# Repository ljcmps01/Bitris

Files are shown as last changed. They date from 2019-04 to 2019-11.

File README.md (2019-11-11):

# Bitris
Proyecto de instalaciones industriales
Se trata de un juego el cual consta de controlar los leds de una matriz con un boton, la matriz desplazará un bit de izquierda a derecha 
en la fila superior, el jugador tendrá un boton que al presionarlo dejará caer el bit al fondo de la matriz.
El objetivo del juego es que el jugador llene todas las filas de la matriz pero siempre una fila a la vez; si el jugador comienza a apilar
La siguiente fila sin haber completado la que se encuentra, perderá una vida, a medida que vaya llenando las filas el juego se volverá mas
veloz.

## Changelog:

_28-03 Funcionamiento de la matriz (delay)_

_10-04 Control de la matriz (Habilitacion de que leds prender)_

_11-04 Funcionamiento de la matriz (TIMER)_

_12-04 Multiplexado de la matriz (Prescaler a 1024 con OCR1A=3,5,8)_

_12-04 Control de velocidad de niveles y desplazamiento del jugador_

_12-04 Deteccion del boton del jugador y animacion de caida (velocidad constante)_

_13-04 1er ensamble: Multiplexado+Desplazamiento+boton+caida_

_13-04 Se agrega la capacidad de mantener el led prendido en el fondo tras realizar la animacion de caida_

_13-04 Se le agrega control de vida y nivel (La vida es solo visual y no afecta el juego todavia)_

_17/04 Se creó programa con animaciones basicas, horizontales y verticales_

_17/04 El boton da inicio al primer juego, se agregó animación cuando se pierde y reinicio con el boton_

~~**[Arreglar falso inicio]**~~

_22/04 VerticalClean, HorizontalClean, Blink pasadas a TIMER_

_23/04 animacion de FillUp pasada a TIMER_

_23/04 Renovacion de Bitris con animaciones de inicio, perdida y victoria (En timer), Falso inicio arreglado_

_23/04 Definiciones Globales del juego_

---------------**FIN DEL CUERPO PRINCIPAL**----------------

_24/04 Creado programa de Display de vida y nivel con CD4511_

_24/04 Acoplado el control de displays al programa principal_

_30/07 Realizado programa para Arduino UNO_

_30/07 Realizado PCB de placa principal_

_13/08 Realizado PCB de placa displays_

_16/08 Adjuntado informe del proyecto_

_19/08 Agregado Diseño 3D del gabinete_

_03/09 Arreglo de diseño de PCB principal_

_12/09 Diseño 3D de la rampa de las monedas_

_20/09 Diseño 3D de la matriz LED_

_08/10 Diseño 3D divididos en partes del gabinete_

_08/10 Conclusion de codigo Bitris Pago_

_05/11 Se agregó la musica principal del juego_

_06/11 Se realizaron pruebas en protoboard con el parlante para un decente sonido_

_08/11 Se realizó el esquematico del amplificador_

_11/11 Arreglado problemas de la musica_

_11/11 Realizado programa de pago CON MUSICA_

## Bugs/Trabajo por hacer:

### Software 

* **LED fantasma**

* **Doble pulsacion**

* Agregar sonido (Principal hecho, falta perdida de vidas, punto, nivel, fin ganado, gameover)

### Hardware 

* Diseñar amplificador (PCB)

* Montar placas (Resta amplificador)

## Creadores

Alejo Rodrigo Campos (@ljcmps01):

* -_Primer programa de control Arduino MEGA_-

* -_Primer diseño SCH y PCB_-

* -_Modelos en 3D_-

Alex Obregon (@alobre4148):

* -_Programa compatible Arduino UNO_ (Programa a utilizar para producto final)-

* -_Diseño PCB final placa principal_-

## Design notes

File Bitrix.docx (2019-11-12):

# Bitrix

El informe deberá tener como mínimo:

1) Caratula con nombre del proyecto y datos de los integrantes
2) Objetivo
3) Breve descripción (esquemas, diagramas, etc.)
4) Principio de funcionamiento y fundamentos teóricos (ecuaciones, graficos,etc)
5) Circuitos electronics (esquemáticos)
6) Modelo de circuito impreso (PCB) lado de cobre y componentes
7) Lista de componentes, costos
8) Posibles aplicaciones
9) Indice

# Introducción

Este proyecto propone crear un Tetris “de un bit”, a diferencia del Tetris común, este no tendrá formas complejas como la L,T, el cubo o el palo; únicamente dispondrá de un único punto (un led) que ira de izquierda a derecha en lo más alto de la pantalla. Una vez el jugador apriete un botón, se dejará caer este bit a lo más profundo de la pantalla, el objetivo es que el jugador vaya alineando horizontalmente bit por bit como se muestra en el siguiente gráfico.

1 | | | 9

Una vez la fila es completada el jugador pasará de nivel y deberá proseguir a llenar la siguiente fila, a medida que el desplazamiento del bit superior va aumentando de velocidad.

El desafío del juego se encuentra en que el jugador NO debe comenzar a llenar la siguiente fila sin haber completado la anterior (ejemplo en el grafico debajo). Si esto llegara a suceder el jugador perderá una de sus vidas.

| | | | | | | El jugador comenzó a completar la 2da
| | | | | | | Fila sin completar la 1ra
0 | | | | | | 8

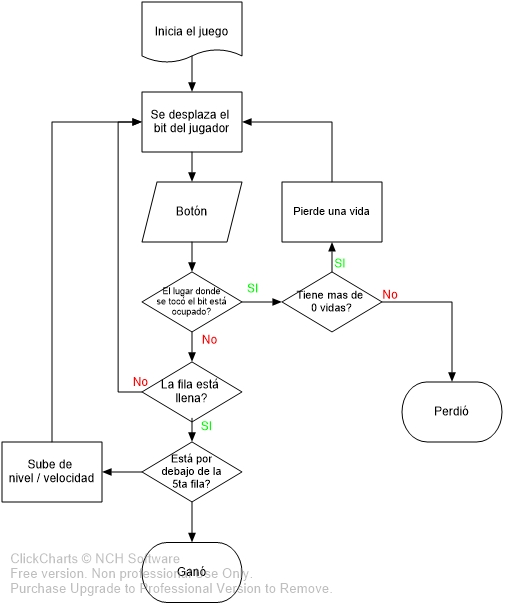
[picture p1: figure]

Debido a que a medida que suba de nivel se aumentará la velocidad de desplazamiento, al jugador se le hará más difícil completar adecuadamente las filas.

Para tener una mayor comprensión del funcionamiento y de lo que se encargará el futuro programa, se realizó el siguiente diagrama de flujo simplificado

El gabinete del juego está hecho a partir de un metro cuadrado de chapa galvanizada de 0,3mm de espesor.

Pero a su vez también se realizaron los diseños de los mismos utilizando AutoCAD para poder visualizar el aspecto final del gabinete y ayudar a la hora de toma de decisiones en cuanto a la estética del proyecto y comodidad para el usuario.

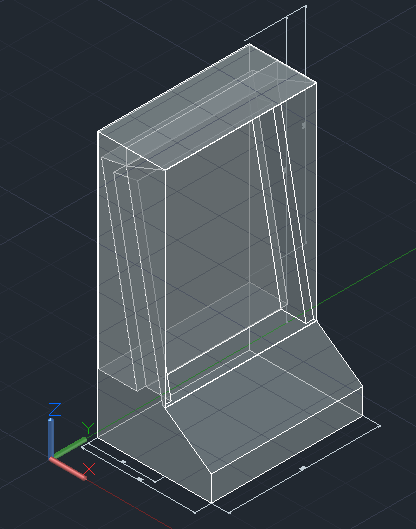
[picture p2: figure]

Esto nos permitió tener acceso a figuras 3D que pueden ser impresas fácilmente en una impresora 3D

# Principio de funcionamiento

## Matriz y multiplexado

Debido a la limitada cantidad de pines disponibles en el microcontrolador y a la poca energía que estos pueden entregar en su salida, se debió utilizar técnicas de multiplexado, tanto para el control de la matriz 6x4 como para los displays de vida restantes y nivel.

Para esto se utilizó uno de los timer del ATMEGA 328p en modo de comparación con un prescaler de 1024 y un valor de comparador de 3. Con esto en una frecuencia de aproximadamente 16MHz nos da una función de multiplexado que se activa cada:

1/(16MHz)×1024×3=0,000192 seg

O sea, con una frecuencia de:

1/(192μSeg)=5,2KHz

Si bien esto está muy por encima de la frecuencia de 50Hz necesaria para que el ojo humano no distinga el prendido y apagado, se optó por esta velocidad ya que el programa debe realizar el maskeo completo de la matriz y modificar los valores de los displays dentro de estos intervalos.

Por lo que la frecuencia real de multiplexado completo es el intervalo entre cada activación de la función dividido cada led de la matriz:

(5,2KHz)/(4×6)=217Hz

Si bien sigue siendo más de 4 veces la velocidad requerida, preferimos utilizarla de todas maneras ya que no afecta el funcionamiento del juego y a la vez conseguimos una visualización del display más limpia que a frecuencias más bajas.

## Display de vidas y nivel

Como se mencionó en el punto anterior, los displays son controlados en parte por multiplexación para mostrar las vidas restantes y el nivel actual.

Pero se presentó la problemática de la cantidad de pines limitados del ATMEGA328p por lo que no era posible controlar directamente los 7 segmentos a través de él utilizando una decodificación por software. En cambio, se decidió utilizar un CD4511 de intermediario.

El CD4511 es un decodificador de binario a 7 segmentos, lo que quiere decir que una vez conectado las entradas correspondientes y las salidas a su respectivo segmento, en el display se vera el numero ingresado en formato binario en las entradas.

De esta forma se ahorran 3 pines que pueden ser utilizados para otras funciones, el programa se simplifica ya que solo hay que poner las salidas en binario, y mas importante, se libera al microcontrolador de la carga de tener que alimentar los 7 segmentos del display, ya que estos serán controlados por el mismo CD4511, el cual es capaz de soportar mayores cargas.

Cabe aclarar dos cosas:

- Debido a este último aspecto se debe poner resistencias para proteger los segmentos
- El microcontrolador se sigue encargando de controlar que display prender (multiplexado) y que valor mostrar (Se lo indica al CD4511)

## Botón

### Jugador

Debido a que este es un juego de reflejos y velocidad nos pareció que debíamos evitar utilizar la técnica de polling* para detectar cuando se presiona el botón. En cambio, se tomo ventaja de una de las interrupciones externas del ATMEGA328p, de esta forma el programa dentro del microcontrolador reaccionará de forma casi instantánea cada vez que el botón sea presionado.

*Consiste en realizar una lectura lo mas frecuentemente posible del estado un pin para determinar si hubo un cambio de estado

Esta interrupción será activada cuando ocurra un flanco descendente en el pin 4 del microcontrolador.

Para la elección del botón se tomó como principal parámetro la estética y sensación del mismo al presionarlo.

### Monedas

En el caso de la detección de monedas se optó por realizar una ranura en el frontal del gabinete que dirija a una rampa que vaya recolectando las monedas insertadas. Dicha rampa tiene un foto-interruptor incrustado el cual detectará el paso de la moneda.

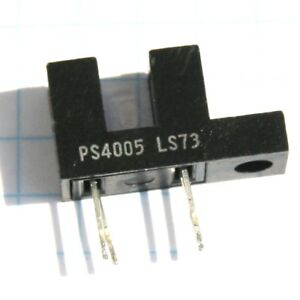
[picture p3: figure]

Se decidió utilizar un PS4005 por su simplicidad de uso.

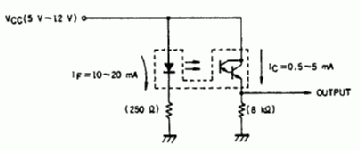
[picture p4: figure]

Como la esquemático interno indica, en su interior no hay más que un LED y un fototransistor

Para hacerlo funcionar de la manera deseada solo se necesita poner unas resistencias de pull up y de limitación de corriente para el LED

El foto-interruptor estará constantemente mandando un 1 en el pin 2 del ATMEGA; cuando pase un objeto entre se el LED y el fototransistor, la señal se irá a masa.

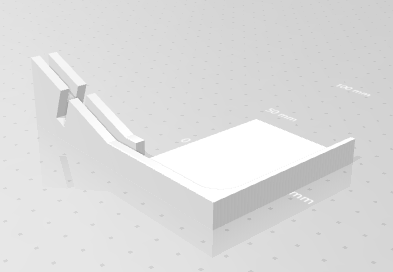
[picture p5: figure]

Por medio del software se configuro que esto solo pueda ser activado para iniciar el juego, durante el resto del juego las señales recibidas por el interruptor serán ignoradas. De la misma forma que las señales recibidas del botón del jugador serán ignoradas hasta que el mismo inserte una moneda/ficha.

La rampa fue realizada en AutoCAD para que pueda ser impresa en 3D fácilmente, con la ranura para el foto-interruptor

## Música/amplificación

Para añadirle más carisma al juego se le puso música de fondo. La cual sonará a través de un parlante de 4 Ω

Esto se realizó utilizando la librería Tone de Arduino, la cual fue creada para este mismo propósito. Aun así, el pin del Arduino no es capaz de hacer sonar el parlante utilizado, o por lo menos no con el volumen deseado.

Por esto se decidió hacer una amplificación simple con un optoacoplador (4n28) y un transistor que soporte la carga presentada por el parlante.

Realizando pruebas se encontró que el parlante puede llegar a consumir hasta 350mA aprox. Con una alimentación de 9V. Teniendo en cuenta esto se decidió utilizar un BD137, el cual es un transistor NPN capaz de soportar una corriente de colector de 1,5A.

Como detalle interactivo, la música cambiará su velocidad a medida que el jugador vaya aumentando de nivel.

# Circuitos electrónicos

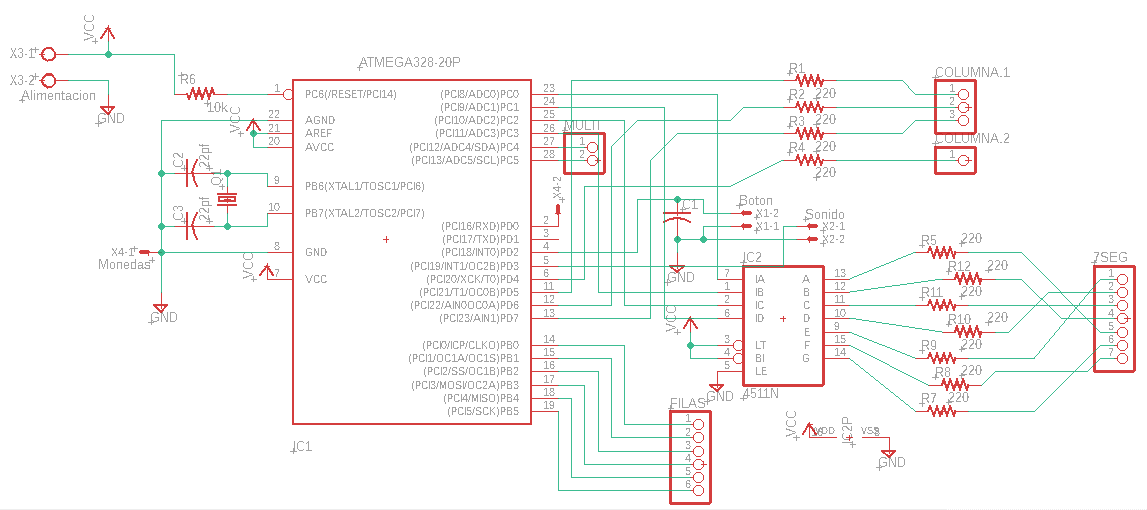
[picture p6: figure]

## Placa controladora

## Placa de displays 7 segmentos

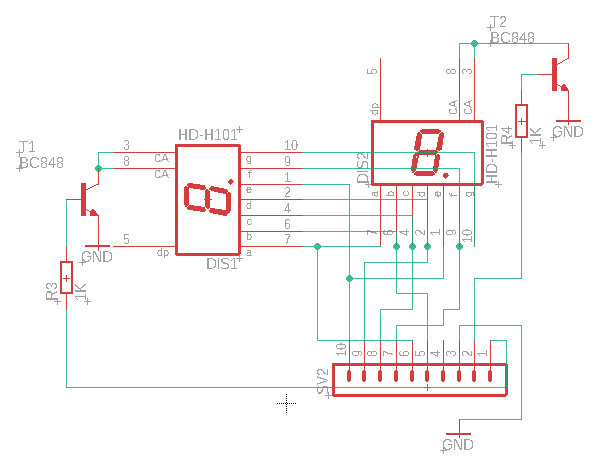
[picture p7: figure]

## Placa de amplificación de audio

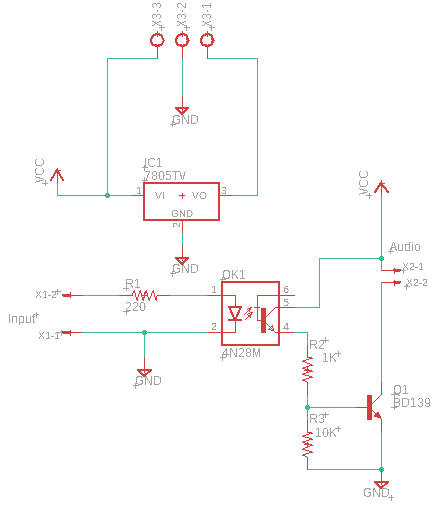
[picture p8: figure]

# Diseño PCB

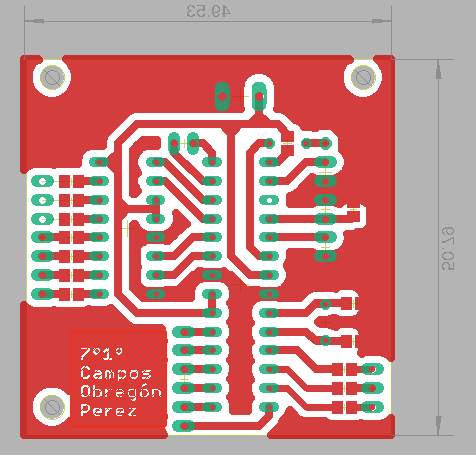
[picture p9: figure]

## Placa controladora

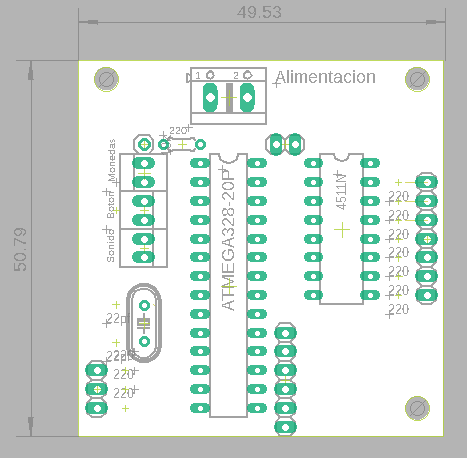
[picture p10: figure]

## Placa de amplificación de audio

## Placa de displays 7 segmentos

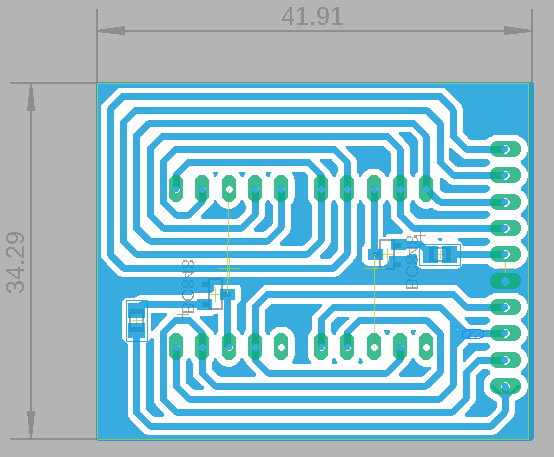
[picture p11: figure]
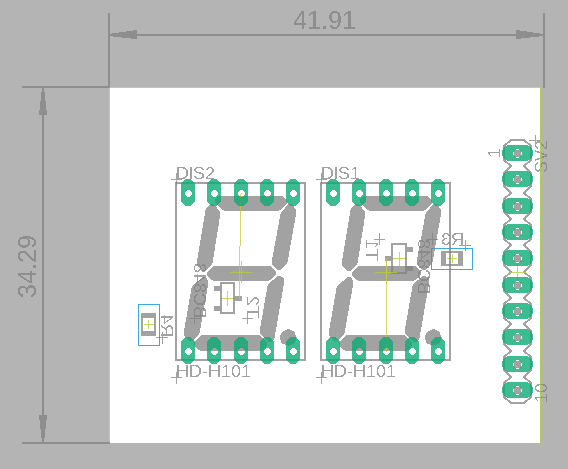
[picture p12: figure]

# Aplicaciones

El Producto en si es solo un juego por lo que no tiene aplicación útil en si, pero es un producto didáctico que como tal puede ser vendido a salones de Arcade.

Ademas si bien el producto planteado como tal puede ser robusto y pesado, este se puede utilizar en diferentes configuraciones

# Lista de componentes

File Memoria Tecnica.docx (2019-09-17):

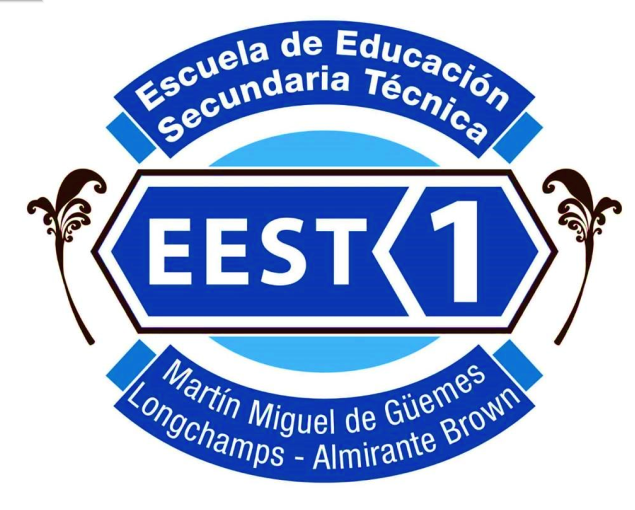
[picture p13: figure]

# Bitrix

Trabajo de instalaciones industriales

Alejo Rodrigo Campos

Alex Obregón

Tomas Perez

7° 1°

27/08

# Introducción

Este proyecto propone crear un Tetris “de un bit”, a diferencia del Tetris común, este no tendrá formas complejas como la L,T, el cubo o el palo; únicamente dispondrá de un único punto (un led) que ira de izquierda a derecha en lo más alto de la pantalla, una vez el jugador apriete un botón, se dejará caer este bit a lo más profundo de la pantalla, el objetivo es que el jugador vaya alineando horizontalmente bit por bit como se muestra en el siguiente gráfico.

1 | | | 9

Una vez la fila es completada el jugador pasara de nivel y deberá proseguir a llenar la siguiente fila, a medida que el desplazamiento del bit superior va aumentando de velocidad.

El desafío del juego se encuentra en que el jugador NO debe comenzar a llenar la siguiente fila sin haber completado la anterior (ejemplo en el grafico debajo). Si esto llegara a suceder el jugador perderá una de sus 3 vidas.

| | | | | | | El jugador comenzó a completar la 2da
| | | | | | | Fila sin completar la 1ra
0 | | | | | | 8

# Características

## Software

El programa del juego será el encargado de realizar el funcionamiento lógico del juego, en la misma ira tanto la configuración del juego (vidas, niveles, velocidad, etc)

Como el lógico del resto del hardware.

### Configuración del juego:

Vidas: determina la cantidad de vidas que tiene el jugador

Selector de nivel: determina en que nivel se encuentra el jugador

Nivel: es un vector que tiene una cantidad de elementos igual a la cantidad de filas de la matriz, cada elemento tiene un valor especifico que determina la velocidad del juego en base a los ciclos que realiza el oscilador del uC.

### Control lógico del hardware

Display: determina que numero muestran los Display de 7 segmentos tomando el valor de las variables Selector de nivel y Vida.

Multiplexado: es una variable boolean que se utiliza para multiplexar los Display

Filas: posee la altura (cantidad de filas) de la matriz y en base a ella se determina la cantidad de niveles del juego, se usará para el control de la matriz y mostrar animaciones junto con Columnas

Columnas: posee el ancho (cantidad de columnas) de la matriz y se usará para el desplazamiento del jugador, y determinar en qué posición se encuentra, también se usará para mostrar animaciones junto con Filas

Sonido: se utiliza para realizar las diferentes melodías del juego

## Hardware:

Posee 3 partes principales ara el funcionamiento del juego, obviando la alimentación.

### Matriz LED

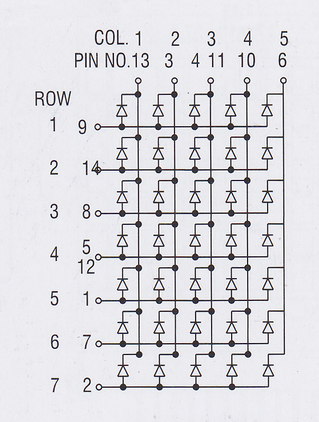
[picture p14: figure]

Se trata de una matriz led de 6x4 la cual será la pantalla del juego por lo cual se trata de la parte mas importante del juego ya que sin ella el jugador no tendría idea de lo que sucede

### Displays

Son dos displays de 7 segmentos ubicados en los extremos del frente del gabinete, uno mostrará las vidas restantes mientras que el otro se encargará de mostrar en el nivel está el jugador, se controlaran mediante un CD4511 que traduce de binario a 7 segmentos y además mediante dos transistores con el fin de multiplexar los valores que mostrará cada display

### Buzzer

Es un piezoeléctrico que se encargará de darle mas “vida” al juego, emitiendo las melodías dependiendo la situación del juego, necesita amplificador?

# Problemáticas

## Consumo

Al haber de por medio una matriz (la cual contiene 24 leds), 2 displays (cada uno de 7 leds) y un parlante piezoeléctrico que deben ser controlados por un uC se debe tener especial cuidado con la corriente que todo esto llegue a exigirle al integrado ya que este es de baja potencia

### Solución

El principal problema se encuentra en la gran cantidad de led a manejar, ya que idealmente el ATMEGA no puede entregar más de 200 mA. La solución mas viable encontrada es el multiplexado para el control de la matriz.

Utilizando esta técnica, la matriz tendrá el consumo equivalente a un solo led a pesar de que visualmente pareciera que la matriz estuviese completamente prendida si así se deseara.

Por otro lado, el uC pasará a ser solo la entrada de un amplificador que se encargará de amplificar la señal para el piezoeléctrico

El control de los Displays se realizará utilizando un 4511 y multiplexado, no solo para la problemática del consumo si no que también ayuda con otra problemática, la cantidad de pines.

## Cantidad de pines

En principio necesitaríamos:

- 7 pines por display (x2)
- 10 pines para la matriz
- 1 para las melodías
- 1 para el botón del jugador

El problema esta en que el ATMEL solo dispone de 20 pines para uso del usuario y según la lista anterior, se necesitarían unos 26 pines lo cual ya a primera vista puede dejarse ver el conflicto, no solo eso, también que hay ciertas partes que necesitan estar vinculados a un pin especifico, como el piezoeléctrico, debe ir conectado a un pin de PWM y el botón del jugador, para una mejor precisión de lectura debe ir conectado a un pin de interrupción externa

### Solución

Como se mencionó en el apartado de consumo, los displays se controlarán con un CD4511, el cual es un integrado que se encarga de procesar la señal del microcontrolador (en binario) para mostrar el numero enviado en el display. Esto reduciría la cantidad de pines requeridos por los displays de 14 a 8, y gracias a la técnica de multiplexado este número decrece a solo 6 pines; 4 para enviar el numero en binario y 2 para alternar (multiplexar) que numero prender.

Esta problemática también fue la principal razón por la que se decidió utilizar una pantalla matricial ya que si cada led tuviera su propio pin dedicado se necesitarían 24 pines solo para los leds.

## Alimentacion

A la hora de plantear el diseño del esquemático se debió considerar que niveles de tensión manejaría el proyecto.

El principal foco esta en el microcontrolador ya que estos componentes suelen ser los mas delicados y trabajan en angostos rangos de tensión (3,3v a 5,5v).

También se tuvo en cuenta la potencia que se buscaría obtener en el amplificador, esta debería ser suficiente como para ser escuchada en un ambiente de salón de juegos o la muestra escolar.

Teniendo en cuenta que el ATMEGA 328p se maneja con 5v, determinamos que esta tensión seria ideal para el control lógico pero no para el circuito de amplificación ya que necesitaríamos relativamente grandes niveles de corriente para que tenga una potencia ideal. Es por esto que decidimos utilizar una tensión principal de 9v y con un regulador de tensión de 5v que derive la tensión correspondiente para el microcontrolador.

El 4511 es despreciado ya que este trabaja en un amplio rango de tensión (3v a 18v).

## Diseño del Esquematico y PCB

En base al código y las pruebas realizadas en la placa de desarrollo Arduino UNO se planteó un esquemático guía de como se realizarán las conexiones en la placa principal la cual consiste principalmente del ATMEGA 328p y el 4511 junto con los pines que transmitirán las señales a las diferentes plaquetas y partes del sistema, los displays 7 segmentos y la matriz led como ejemplos.

Teniendo en cuenta lo mencionado se realizó este esquemático:

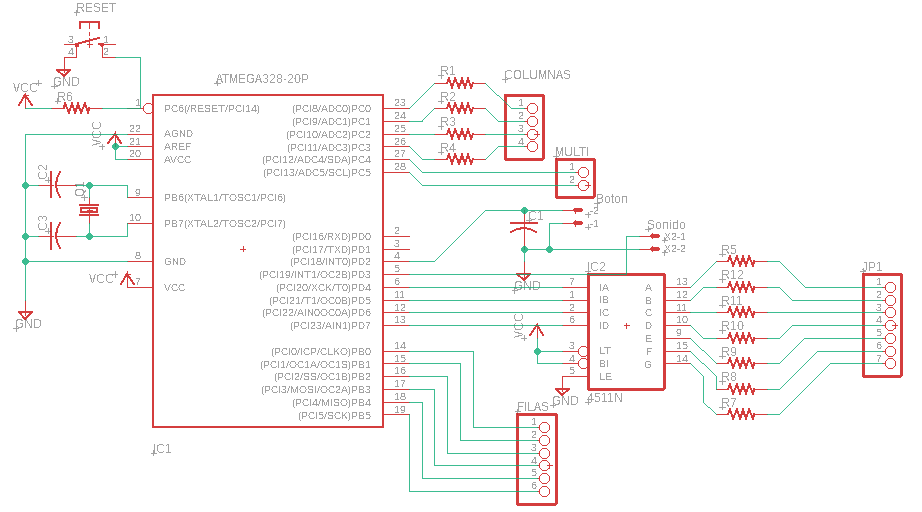
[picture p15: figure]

Posteriormente se procedió a diseñar el PCB, en el cual se tuvo en cuenta los siguientes parámetros:

- Tamaño, si bien no es tan importante en el diseño de un prototipo, si las plaquetas son mandadas a producirse de forma masiva, el tamaño pasa a ser un parámetro crucial ya que mientras mas pequeña sea la el diseño, mas cantidad de placas se podrán realizar por oblea, siendo importante para el precio final del producto.
- Comodidad, como la plaqueta tiene varias conexiones con otras partes del proyecto estas serán realizadas por conexión de pines por lo que estos deberán ser posicionados en un lugar donde sea fácil de encastrar o desencastrar.
- Estética, se trató de mantener los componentes lo más alineados y paralelos posibles para conservar un diseño estético y fácil de entender.

Vista superior
Pistas

# Gabinete del proyecto

Ya desde la conceptualización del proyecto se pensó en la forma final del proyecto, este tenia un diseño vertical con el panel de control en diagonal. Se hizo un boceto rápido para tener una guía visual

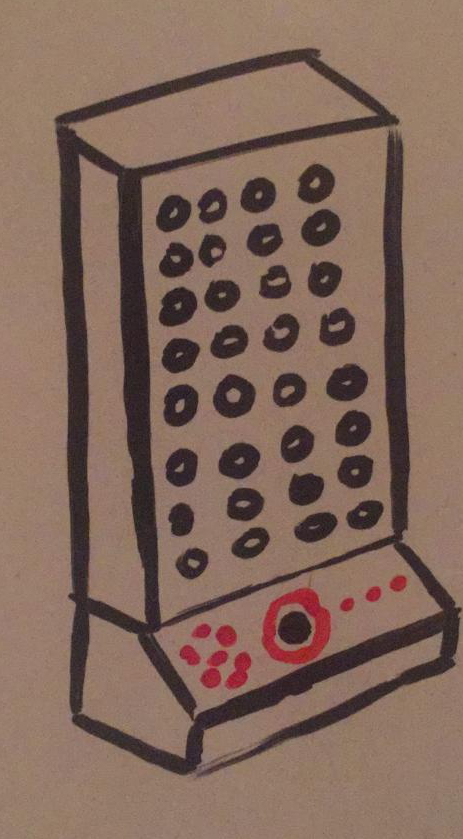
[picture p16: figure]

A simple vista se puede notar que este boceto difiere a lo mencionado anteriormente, por ejemplo, los puntos rojos al lado del botón del medio iban a representar las vidas restantes, mas tarde llegamos a la conclusión de que esto tenia dos problemas:

1. Cada led iba a requerir 1 pin que aunque parecieran pocos eran cruciales para la cantidad de pines i/o disponibles.
2. Si en el futuro queríamos modificar la cantidad de vidas íbamos a tener que rediseñar la plaqueta y modificar el gabinete

Nos dimos cuenta que utilizar un segundo display utilizando multiplexado nos iba a costar menos pines y además íbamos a tener una mayor flexibilidad a la hora de configurar la cantidad de vidas

Una vez realizado el programa del proyecto, la matriz LED y las plaquetas realizadas en EAGLE ya pudimos darle forma con medidas precisas al gabinete que decidimos utilizar

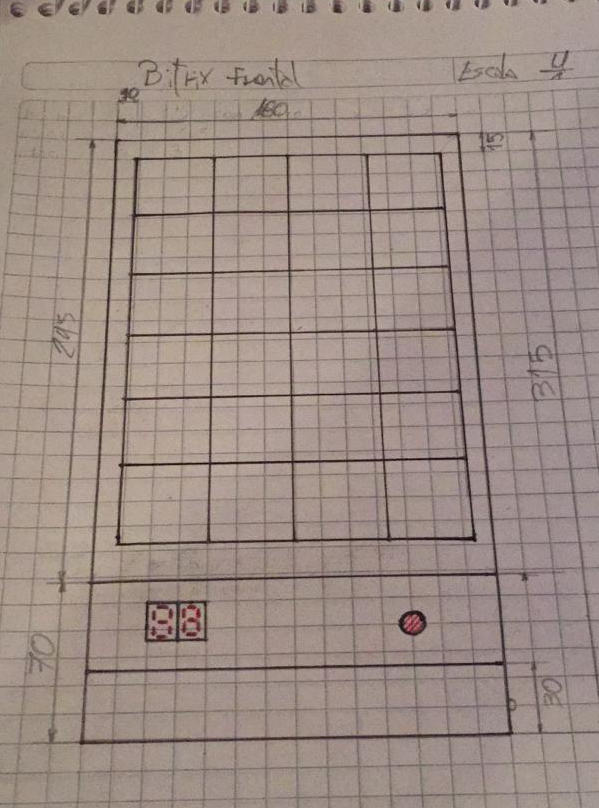
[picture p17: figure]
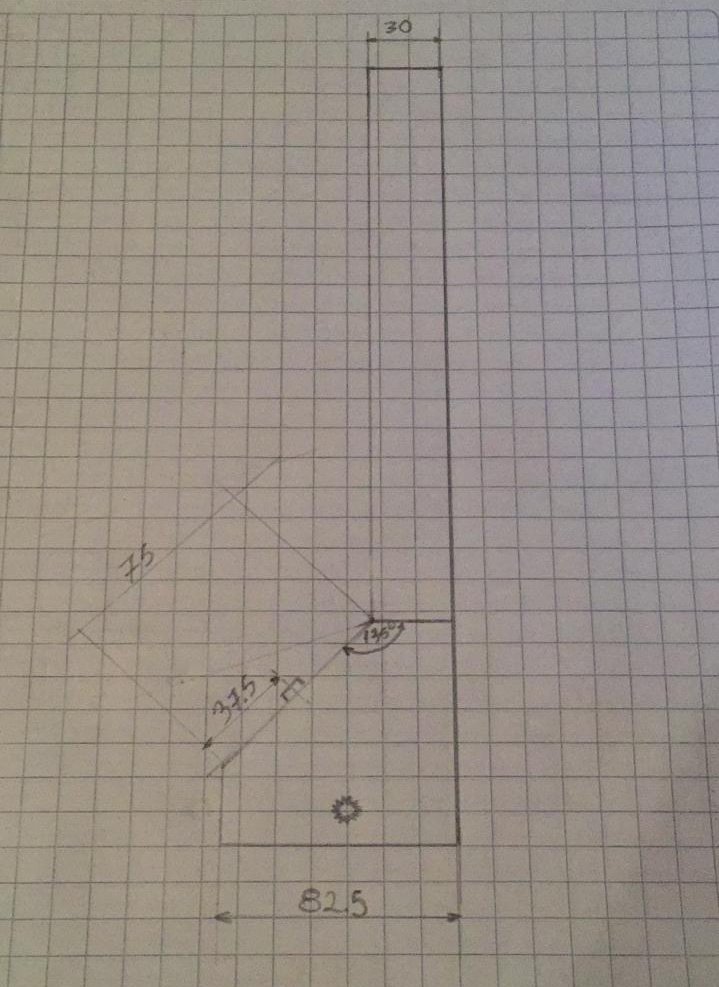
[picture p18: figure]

En base al borrador anterior se realizo un croquis con las medidas precisas de la matriz y procurando dejar suficiente espacio para las plaquetas.

Vista Lateral Derecha 1

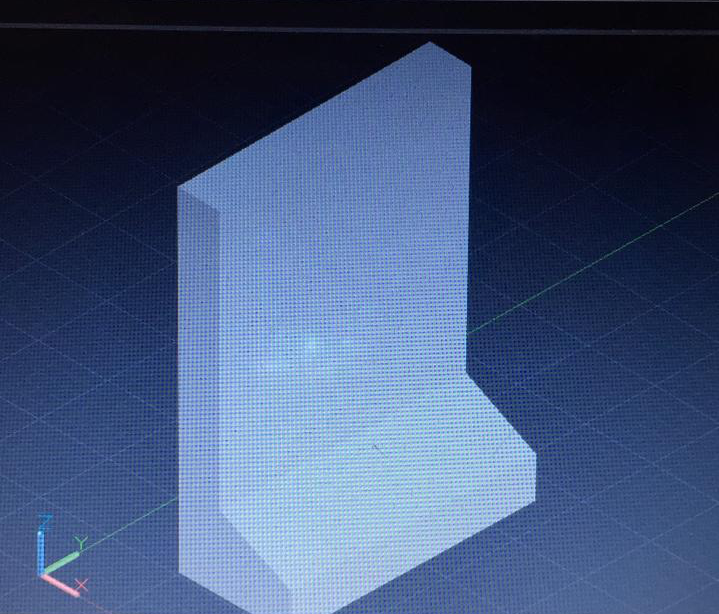
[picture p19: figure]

Diseño en AutoCAD 1

Vista Frontal 1

Ya en esta versión se puede observar una mayor cantidad de detalles en las medidas y posicionamiento de los elementos, se movió el botón (Circulo rojo) a un lado mas cómodo para la mano y se puede observar la ubicación final de los displays y la mueca lateral que representará el control del volumen del juego

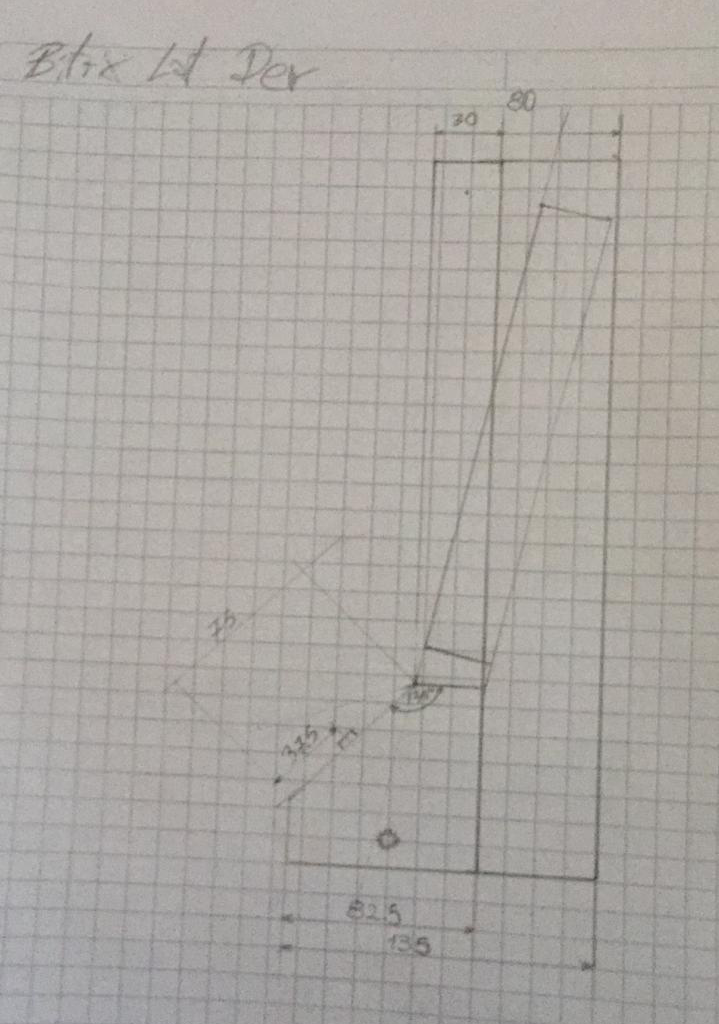
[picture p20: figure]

Si bien es un boceto mas prolijo y con mas forma, terminamos decidiendo que puede mejorarse especialmente estéticamente por lo que se hizo unas modificaciones a la vista derecha para inclinar ligeramente la matriz quedando de la siguiente forma:

- Se mantuvieron todas las líneas del diseño anterior para una fácil comparación
- Se dibujo la matriz con su respectivo tamaño inclinado
- Se debió alargar tanto la parte superior como la base del gabinete para que cupiera la matriz

Y en base al croquis modificado se volvió a realizar un diseño 3D:

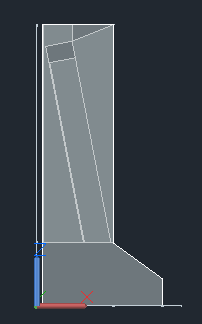
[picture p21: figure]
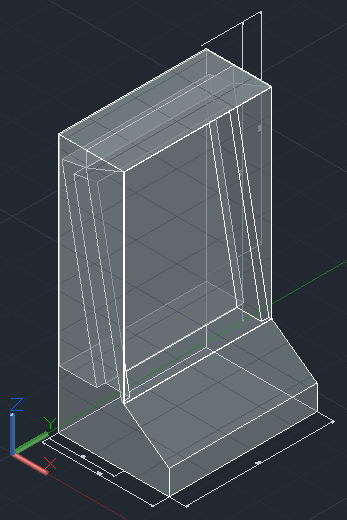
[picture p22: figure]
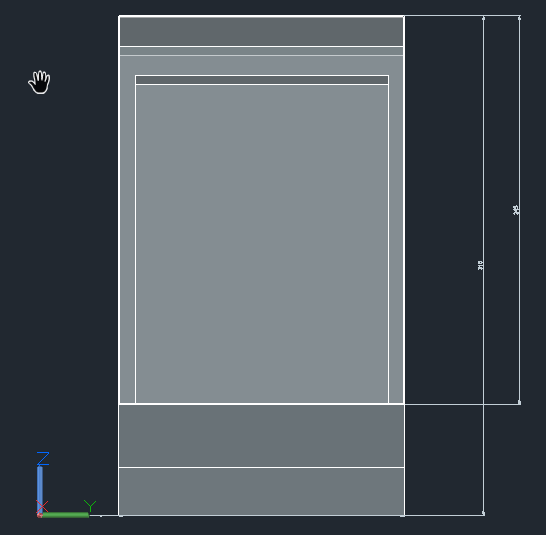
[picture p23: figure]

- Teniendo esta vista se comprobó que de esta forma el juego tiene mayor “estilo” y se ve mas agradable a la vista

# Seguimiento del proyecto

Todo avance desde el comienzo y conceptualización del proyecto fue siendo agregado a un repositorio de GitHub donde se puede acceder a toda la información de parte por parte del programa, esquemáticos y PCB e incluso este informe

El link al repositorio se encuentra aquí (https://github.com/ljcmps01/Bitris)

## Contenidos

- .../BitrisPCB: Contiene los archivos relacionados con el diseño de las plaquetas del proyecto (Esquematicos y PCB)
- …/Codigo: Contiene todos los codigos utilizados, incluyendo el principal (BitrisUNO)
- …/Diseño del gabinete: Contiene el diseño en CAD del gabinete del juego
- …/Pruebas del código: Videos del progreso del código
- …/Informe del Bitrix: Este mismo documento
- …/README: Un archivo .txt con un historial de cada actualización del repositorio

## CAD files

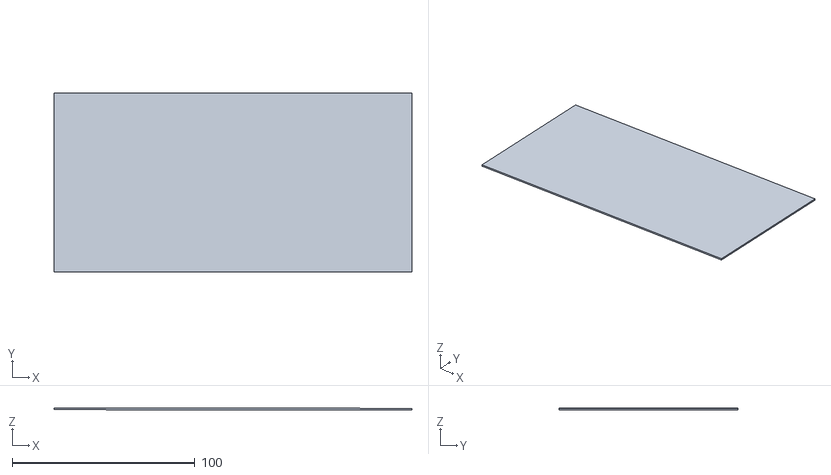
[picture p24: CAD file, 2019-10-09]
GabineteDesign/BackCase.stl
196.0 x 98.0 x 1.25

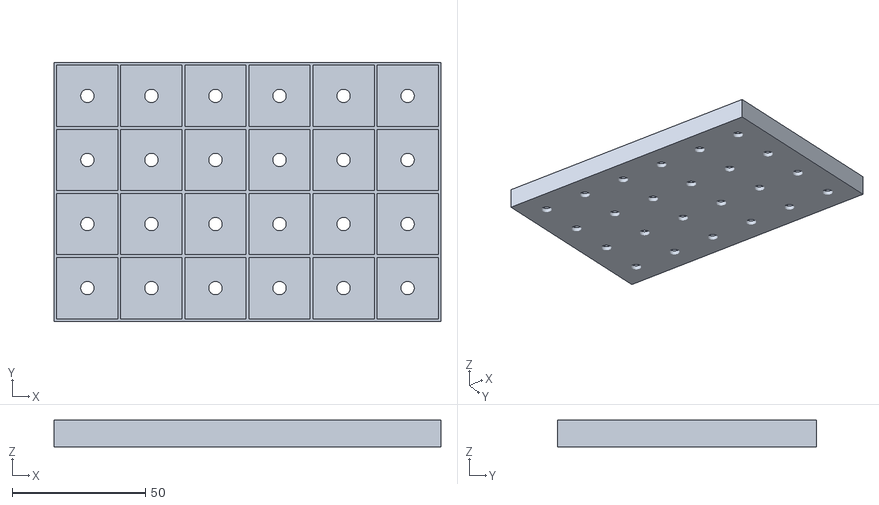
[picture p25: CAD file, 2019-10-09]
GabineteDesign/MatrizLED.stl
145.0 x 97.0 x 10.00

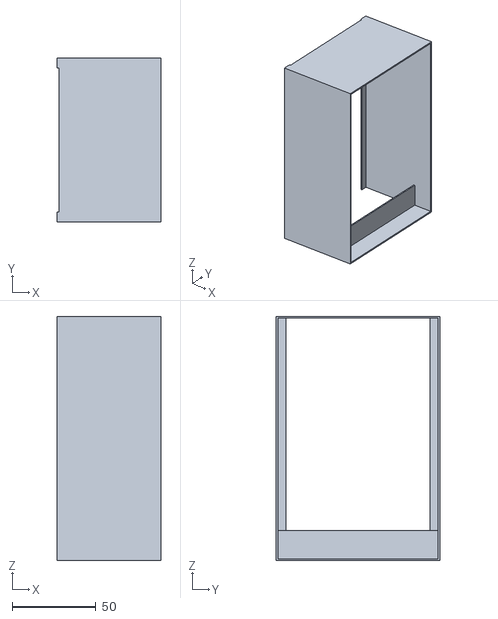
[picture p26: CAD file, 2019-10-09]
GabineteDesign/TopCase.stl
62.0 x 98.0 x 146.0

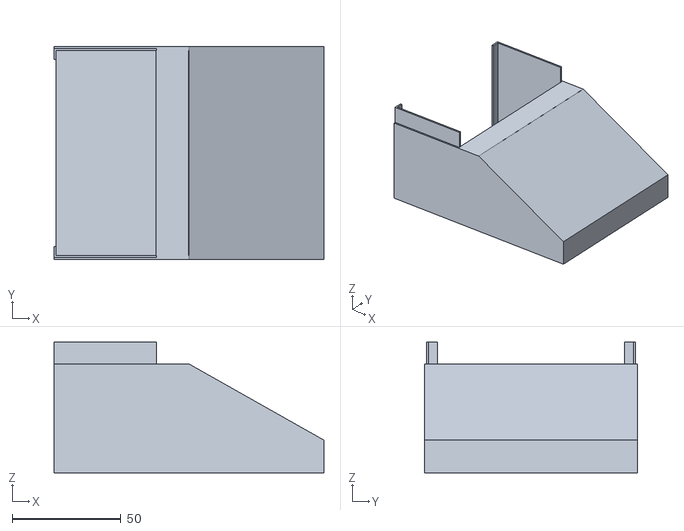
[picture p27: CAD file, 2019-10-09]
GabineteDesign/LowCaseBitrix.stl
124.0 x 98.0 x 60.0

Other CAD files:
GabineteDesign/GabineteDividido.dwg
GabineteDesign/MatrizLED2.dwg
GabineteDesign/Monedas.dwg
GabineteDesign/GabineteMatrizVertical.dwg
GabineteDesign/MatrizLED.dwg

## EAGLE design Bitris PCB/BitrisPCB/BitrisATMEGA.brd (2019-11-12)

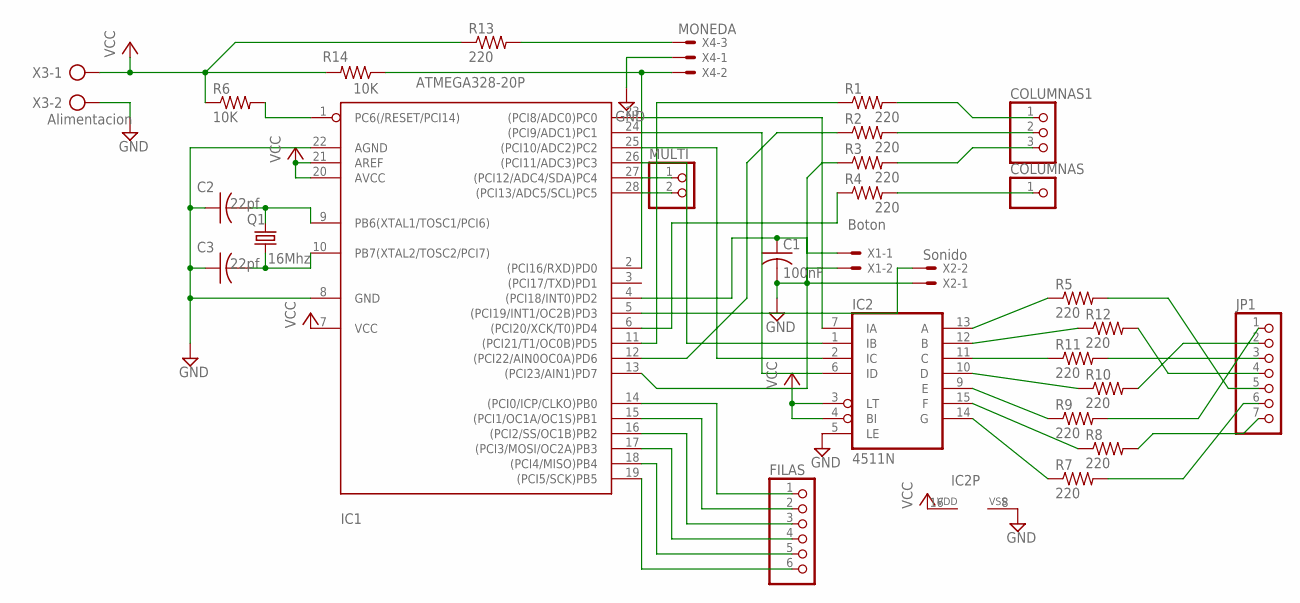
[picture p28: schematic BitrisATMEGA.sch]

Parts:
C1: 100nF; C0805
C2, C3: 22pf; C0805
COLUMNAS: PINHD-1X1; 1X01
COLUMNAS1: PINHD-1X3; 1X03
FILAS: PINHD-1X6; 1X06
IC1: ATMEGA328-20P; DIL28-3
IC2: 4511N; DIL16
JP1: PINHD-1X7; 1X07
MULTI: PINHD-1X2; 1X02
Q1: 16Mhz; HC49/S
R1, R2, R3, R5, R7, R8, R9, R10, R11, R12, R13: 220; M0805
R4: 220; 0204/5
R6, R14: 10K; M0805
X1: Boton; 22-23-2021
X2: Sonido; 22-23-2021
X3: Alimentacion; AK500/2
X4: MONEDA; 22-23-2031

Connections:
GND: C1.2, C2.1, C3.1, IC1.8 (GND), IC1.22 (AGND), IC2.5 (LE), IC2.8 (VSS), X1.2, X2.1, X3.2, X4.1
unnamed: COLUMNAS1.1, R1.2
unnamed: COLUMNAS1.2, R2.2
unnamed: COLUMNAS1.3, R3.2
unnamed: COLUMNAS.1, R4.2
unnamed: IC1.23 ((PCI8/ADC0)PC0), IC2.7 (IA)
unnamed: IC1.24 ((PCI9/ADC1)PC1), IC2.6 (ID)
unnamed: IC1.25 ((PCI10/ADC2)PC2), IC2.2 (IC)
unnamed: IC1.26 ((PCI11/ADC3)PC3), IC2.1 (IB)
unnamed: FILAS.1, IC1.14 ((PCI0/ICP/CLKO)PB0)
unnamed: FILAS.2, IC1.15 ((PCI1/OC1A/OC1S)PB1)
unnamed: FILAS.3, IC1.16 ((PCI2/SS/OC1B)PB2)
unnamed: FILAS.4, IC1.17 ((PCI3/MOSI/OC2A)PB3)
unnamed: FILAS.5, IC1.18 ((PCI4/MISO)PB4)
unnamed: FILAS.6, IC1.19 ((PCI5/SCK)PB5)
unnamed: IC1.27 ((PCI12/ADC4/SDA)PC4), MULTI.1
unnamed: IC1.28 ((PCI13/ADC5/SCL)PC5), MULTI.2
unnamed: IC1.6 ((PCI20/XCK/T0)PD4), R4.1
unnamed: IC1.11 ((PCI21/T1/OC0B)PD5), R1.1
unnamed: C2.2, IC1.9 (PB6(XTAL1/TOSC1/PCI6)), Q1.2
unnamed: C3.2, IC1.10 (PB7(XTAL2/TOSC2/PCI7)), Q1.1
unnamed: IC1.13 ((PCI23/AIN1)PD7), R3.1
unnamed: IC2.10 (D), R10.1
unnamed: IC2.11 (C), R11.1
unnamed: IC2.12 (B), R12.1
unnamed: IC2.13 (A), R5.1
unnamed: IC2.9 (E), R9.1
unnamed: IC2.15 (F), R8.1
unnamed: IC2.14 (G), R7.1
unnamed: IC1.2 ((PCI16/RXD)PD0), R14.1, X4.2
unnamed: IC1.5 ((PCI19/INT1/OC2B)PD3), X2.2
unnamed: C1.1, IC1.4 ((PCI18/INT0)PD2), X1.1
unnamed: IC1.1 (PC6(/RESET/PCI14)), R6.2
unnamed: JP1.1, R9.2
unnamed: JP1.2, R10.2
unnamed: JP1.3, R11.2
unnamed: JP1.4, R12.2
unnamed: JP1.5, R5.2
unnamed: JP1.6, R7.2
unnamed: JP1.7, R8.2
unnamed: R13.2, X4.3
unnamed: IC1.12 ((PCI22/AIN0OC0A)PD6), R2.1
VCC: IC1.7 (VCC), IC1.20 (AVCC), IC1.21 (AREF), IC2.3 (LT), IC2.4 (BI), IC2.16 (VDD), R6.1, R13.1, R14.2, X3.1

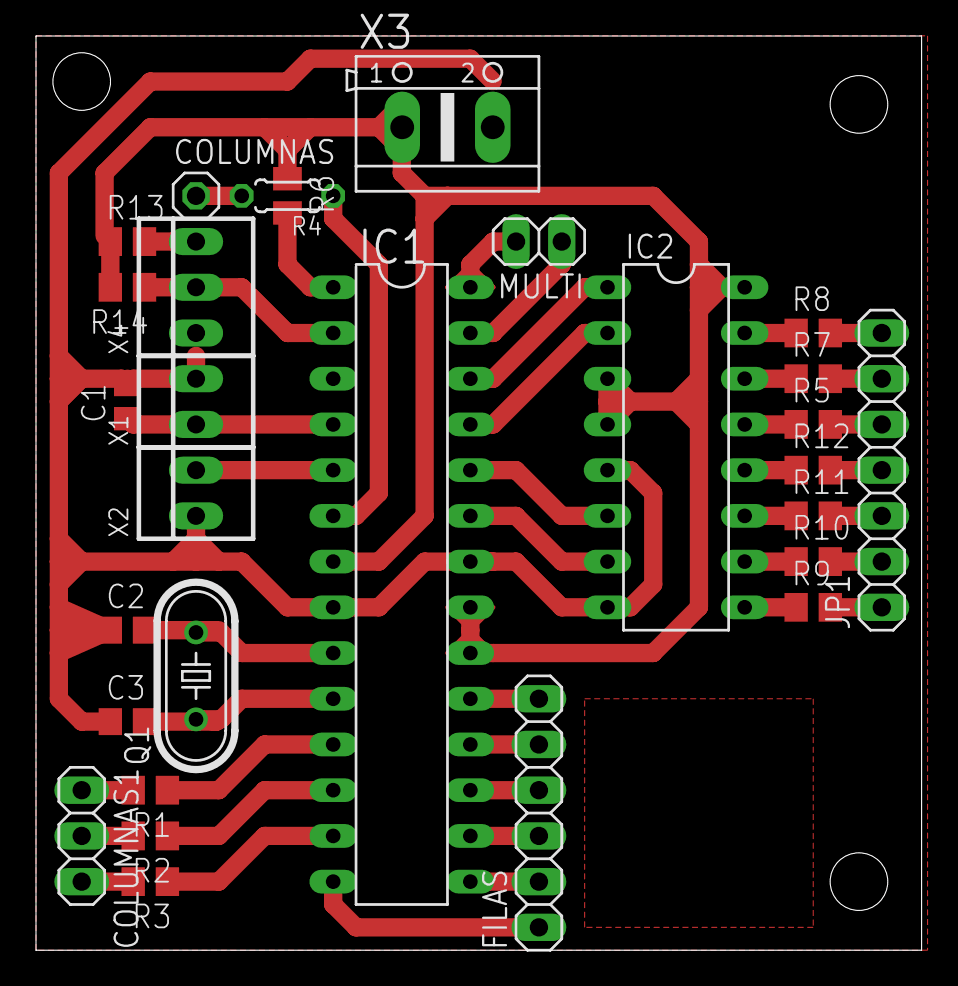
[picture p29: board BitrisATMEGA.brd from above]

Board: 2 copper layers, 49.2 x 50.8 mm, 29 parts (0 on the bottom side), 43 nets.

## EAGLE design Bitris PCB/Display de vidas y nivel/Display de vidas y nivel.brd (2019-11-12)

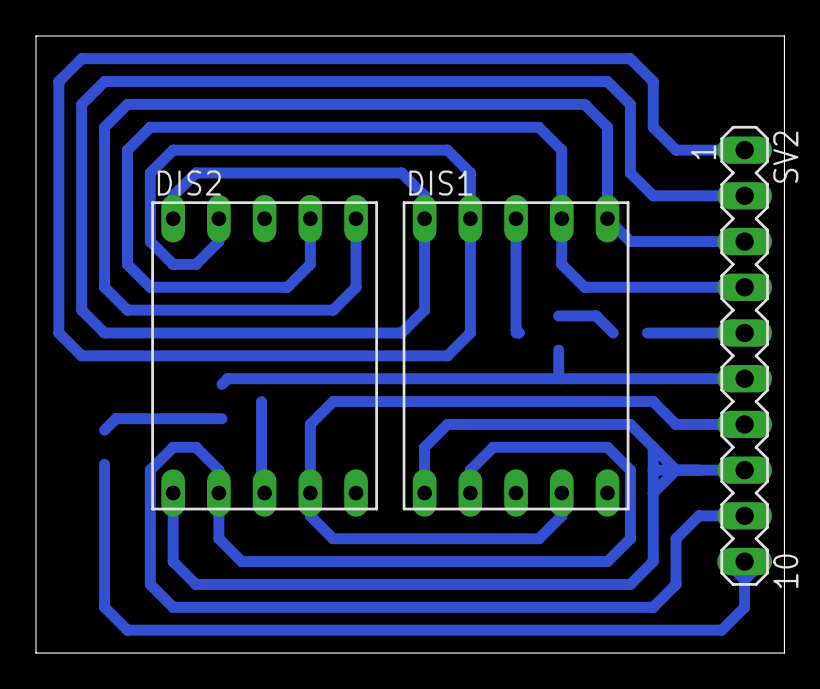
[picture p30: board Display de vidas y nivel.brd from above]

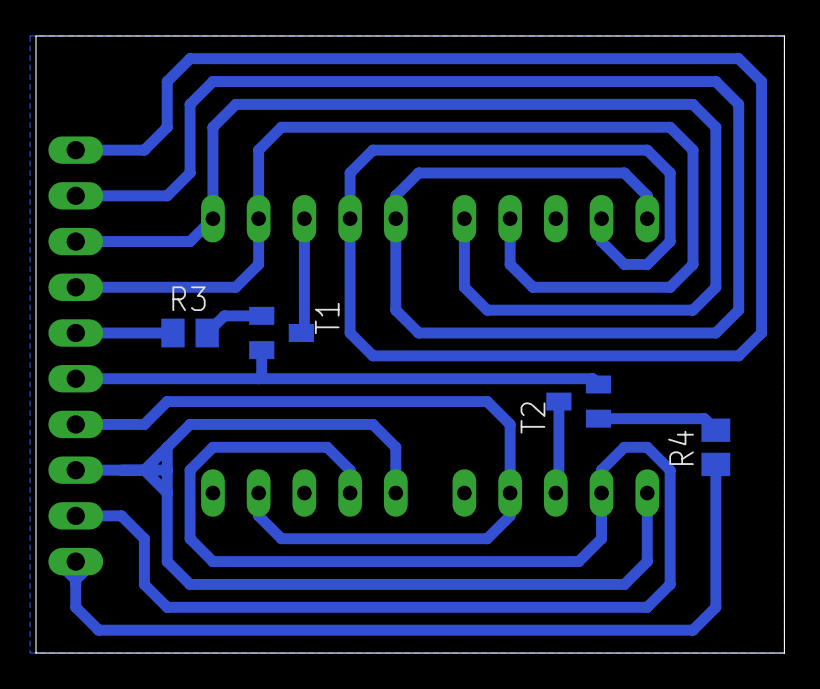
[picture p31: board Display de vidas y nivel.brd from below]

Board: 2 copper layers, 41.6 x 34.3 mm, 7 parts (4 on the bottom side), 14 nets.

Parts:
DIS1, DIS2: HD-H101; HDSP-M
R3, R4: M0805
SV2: MA10-1
T1, T2: BC848; SOT23

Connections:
GND: SV2.6, T1.2, T2.2
unnamed: R3.2, T1.1
unnamed: DIS1.6, DIS2.6, SV2.3
unnamed: DIS1.4, DIS2.4, SV2.7
unnamed: DIS1.2, DIS2.2, SV2.9
unnamed: DIS1.1, DIS2.1, SV2.8
unnamed: DIS1.9, DIS2.9, SV2.1
unnamed: DIS1.10, DIS2.10, SV2.2
unnamed: DIS1.3, DIS1.8, T1.3
unnamed: DIS2.3, DIS2.8, T2.3
unnamed: R3.1, SV2.5
unnamed: R4.2, T2.1
unnamed: DIS1.7, DIS2.7, SV2.4
unnamed: R4.1, SV2.10

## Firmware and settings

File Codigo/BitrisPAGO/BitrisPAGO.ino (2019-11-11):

/*Adiciones:
   Definiciones Globales para configuracion facil del juego
*/
#include "pitches.h"
#define DISPLAY PORTC
#define COL PORTD
#define FILA PORTB

#define VIDAS 9
#define AlturaDeMatriz 5  //Uno menos que el valor real
#define AnchoDeMatriz 3   //Uno menos que el valor real
#define AnimacionVelocidad 500

//Musica
bool musica=0;
int velMusica=500;
int melody[] = {
 
  NOTE_A4, NOTE_G4, NOTE_F4, NOTE_E4, NOTE_C4, NOTE_A3,
  NOTE_D4, NOTE_E4, NOTE_F4, NOTE_G4, NOTE_E4, 0,
  NOTE_D5, NOTE_A4,
  NOTE_F4, NOTE_E4, NOTE_D4,
  NOTE_D4, NOTE_E4, NOTE_F4, NOTE_D4,
 
  NOTE_C4, NOTE_D4, NOTE_A3,
  NOTE_D5, NOTE_A4,
  NOTE_F4, NOTE_E4, NOTE_D4, NOTE_D4, NOTE_E4,
  NOTE_F4, NOTE_G4, NOTE_E4, NOTE_C4,
  NOTE_D4, NOTE_A3, NOTE_D4,
  NOTE_D5, NOTE_A4,
 
  NOTE_F4, NOTE_E4, NOTE_D4,
  NOTE_D4, NOTE_E4, NOTE_F4, NOTE_D4,
  NOTE_C4, NOTE_D4, NOTE_A3,
  NOTE_D5, NOTE_A4,
  NOTE_F4, NOTE_G4, NOTE_A4, NOTE_D4,
  NOTE_E4, NOTE_G4, NOTE_E4, NOTE_C4,
 
  NOTE_D4,
  NOTE_G2, NOTE_G2, NOTE_AS2, NOTE_D3,
  NOTE_F3, NOTE_E3, NOTE_D3, NOTE_A2,
  NOTE_G2, NOTE_G2, NOTE_AS2, NOTE_D3,
  NOTE_F3, NOTE_G3, NOTE_A3,
  NOTE_AS4, NOTE_A4, NOTE_G4, NOTE_F4, NOTE_G4,
 
  NOTE_A4, NOTE_D4, NOTE_A4,
  NOTE_G4, NOTE_G4, NOTE_G4, NOTE_G4, NOTE_F4, NOTE_E4, NOTE_F4, NOTE_G4,
  NOTE_F4, NOTE_G4, NOTE_A4, NOTE_F4,
  NOTE_G2, NOTE_G2, NOTE_AS2, NOTE_D3,
  NOTE_F3, NOTE_E3, NOTE_D3, NOTE_A2,
  NOTE_G2, NOTE_G2, NOTE_AS2, NOTE_D3,
 
  NOTE_F3, NOTE_G3, NOTE_A3,
  NOTE_AS4, NOTE_A4, NOTE_G4, NOTE_AS4, NOTE_C5,
  NOTE_D5, NOTE_A4, NOTE_F4, NOTE_D4,
  NOTE_E4, NOTE_E4, NOTE_E4, NOTE_E4, NOTE_G4, NOTE_E4, NOTE_C4, NOTE_A3, NOTE_C4,
  NOTE_D4, NOTE_D4, NOTE_C4,
 
  NOTE_F4, NOTE_F4, NOTE_F4, NOTE_F4, NOTE_G4, NOTE_A4, NOTE_A4, NOTE_A4, NOTE_G4, NOTE_F4,
  NOTE_E4, NOTE_E4, NOTE_E4, NOTE_E4, NOTE_F4, NOTE_E4, 0, NOTE_F4, NOTE_E4,
  NOTE_D4, NOTE_D4, NOTE_D4, NOTE_D4, NOTE_E4, NOTE_F4, NOTE_F4, NOTE_F4, NOTE_E4, NOTE_D4,
  NOTE_C4, NOTE_C4, NOTE_C4, NOTE_C4, NOTE_D4, NOTE_E4, NOTE_D4, NOTE_C4,
 
  NOTE_AS3, NOTE_AS3, NOTE_AS3, NOTE_AS3, NOTE_C4, NOTE_D4, NOTE_D4, NOTE_D4,NOTE_C4, NOTE_AS3,
  NOTE_A3, NOTE_A3, NOTE_A3, NOTE_F4, NOTE_G4, NOTE_F4, NOTE_C4,
  NOTE_F4, NOTE_F4, NOTE_F4, NOTE_F4, NOTE_G4, NOTE_GS4, NOTE_GS4, NOTE_GS4, NOTE_AS4, NOTE_GS4,
  NOTE_G4, NOTE_G4, NOTE_G4, NOTE_G4, NOTE_GS4, NOTE_G4, NOTE_A4, NOTE_G4,
 
  NOTE_F4, NOTE_F4, NOTE_F4, NOTE_F4, NOTE_G4, NOTE_A4, NOTE_A4, NOTE_A4, NOTE_G4, NOTE_F4,
  NOTE_E4, NOTE_E4, NOTE_E4, NOTE_E4, NOTE_F4, NOTE_E4, NOTE_F4, NOTE_E4,
  NOTE_D4, NOTE_D4, NOTE_D4, NOTE_D4, NOTE_E4, NOTE_F4, NOTE_F4, NOTE_F4, NOTE_E4, NOTE_D4,
  NOTE_C4, NOTE_C4, NOTE_C4, NOTE_C4, NOTE_D4, NOTE_E4, NOTE_D4, NOTE_C4,
 
  NOTE_AS3, NOTE_AS3, NOTE_AS3, NOTE_AS3, NOTE_C4, NOTE_D4, NOTE_D4, NOTE_D4, NOTE_E4, NOTE_G4,
  NOTE_A4, NOTE_A4, NOTE_A4, NOTE_A4, NOTE_C5, NOTE_A4, NOTE_F4,
  NOTE_E4, NOTE_G4, NOTE_A4, NOTE_E4, NOTE_G4, NOTE_A4, NOTE_E4, NOTE_G4,
  NOTE_E4, NOTE_G4, NOTE_A4, NOTE_D5, NOTE_CS5, 0
};

int count = sizeof(melody)/sizeof(int);
 
int noteDurations[] = {
 
  4, 8, 8, 8, 8, 4,
  8, 8, 8, 8, 4, 4,
  2, 2,
  4, 4, 2,
  4, 4, 4, 4,
 
  4, 4, 2,
  2, 2,
  4, 4, 4, 8, 8,
  4, 4, 4, 4,
  4, 4, 2,
  2, 2,
 
  4, 4, 2,
  4, 4, 4, 4,
  4, 4, 2,
  2, 2,
  4, 4, 4, 4,
  4, 4, 4, 4,
 
  1,
  4, 4, 4, 4,
  4, 4, 4, 4,
  4, 4, 4, 4,
  4, 4, 2,
  3, 8, 4, 8, 8,
 
  4, 4, 2,
  8, 16, 16, 8, 8, 4, 8, 8,
  4, 4, 4, 4,
  4, 4, 4, 4,
  4, 4, 4, 4,
  4, 4, 4, 4,
 
  4, 4, 2,
  3, 8, 4, 8, 8,
  4, 4, 4, 4,
  8, 16, 16, 8, 8, 8, 8, 8, 8,
  2, 4, 4,
 
  8, 16, 16, 8, 8, 8, 16, 16, 8, 8,
  8, 16, 16, 8, 8, 4, 8, 16, 16,
  8, 16, 16, 8, 8, 8, 16, 16, 8, 8,
  8, 16, 16, 8, 8, 3, 16, 16,
 
  8, 16, 16, 8, 8, 8, 16, 16, 8, 8,
  8, 16, 16, 8, 8, 4, 4,
  8, 16, 16, 8, 8, 8, 16, 16, 8, 8,
  8, 16, 16, 8, 8, 3, 16, 16,
 
  8, 16, 16, 8, 8, 8, 16, 16, 8, 8,
  8, 16, 16, 8, 8, 3, 16, 16,
  8, 16, 16, 8, 8, 8, 16, 16, 8, 8,
  8, 16, 16, 8, 8, 3, 16, 16,
 
  8, 16, 16, 8, 8, 8, 16, 16, 8, 8,
  8, 16, 16, 8, 8, 4, 4,
  8, 8, 8, 8, 8, 8, 8, 8,
  8, 8, 8, 8, 4, 4
};


//Variables del display
volatile bool Multiplex = 0;
byte Aux1 = 0, Aux2 = 0;

//Variables de desplazamiento del jugador
const int nivel[6] = {15, 12, 10, 8, 6, 4}; //Vector que regula la velocidad del juego
volatile int ContadorDeNivel = 0, nivelSelector = 0;
volatile int pos = 0;                   //Variable que controla la posicion del jugador
volatile bool dir = 0;                  //Variable que controla la direccion del jugador
volatile int contShift = 31;

//Variables de control de la matriz
bool hab[6][4] = {    //Esquema digital de la matriz
  {0, 0, 0, 0},       //Controla que leds se prenden
  {0, 0, 0, 0},
  {0, 0, 0, 0},
  {0, 0, 0, 0},
  {0, 0, 0, 0},
  {0, 0, 0, 0}
};
volatile int fila = 0, col = 0; //Variable que controla que posicion de la matriz verificar

//Variables del boton y animacion de caida
volatile bool boton = 0;
void Drop();
volatile int altura, caida = 0;
volatile int contDrop = 100;
volatile int place;

//Variables del juego
int rowCheck();       //Funcion que checkea cuantos espacios libres quedan en una fila
volatile int vida;  //Variable que controla las vidas del jugador
volatile bool game = 0, start = 0, lost = 0, win = 0; //Game habilita el funcionamiento del juego,
//start le da comienzo
//Lost indica que se perdió

//animaciones
void VerticalEdit(int y, bool value); //Edita columnas
void HorizontalEdit(int x, bool value); //Edita filas
void Clear();                         //Limpia la matriz completamente
void VerticalClean();                 //Hace un barrido vertical
void HorizontalClean();               //Barrido Horizontal
void FillingUp();                     //Llenado de izquierda a derecha
void Blink();                         //Parpadeos
volatile int c_animation = 0, animate = 0, i = 0, j = 0;

void setup() {
  DDRB = 63;
  FILA = 1;
  DDRC |= 0B0111111;
  COL = 80;
  DDRD |= 0b11110000;
  DDRD &= ~(1 << 0);
  Serial.begin(9600);
  cli();                  //deshabilito temporalmente las interrupciones
  TCCR1A = 0;             //limpiamos los registros de control
  TCCR1B = 0;             //del timer 1

  OCR1A = 3;              //3 valor minimo, 5 se ve multiplexado en grabacion de 60fps, 8 valor maximo
  TCCR1B |= (1 << WGM12); //Habilito el Comparador
  TCCR1B |= (1 << CS10);  //Ajusto el prescaler a 1024
  TCCR1B |= (1 << CS12);


  TIMSK1 |= (1 << OCIE1A); //enciendo el timer1

  EIMSK |= (1 << INT0);   //Habilito int0
  EICRA |= (1 << ISC01);

  PCICR = 0;
  PCICR |= (1 << PCIE2);
  PCMSK2 |= (1 << PCINT16);

  sei();                  //activamos las interrupciones
  PORTD = 0;
  PORTD |= (1 << 2);
  PORTD|=(1<<0);
}

void loop() {
  if(musica){
    for (int thisNote = 0; thisNote < count; thisNote++) {
      if(musica){
        int noteDuration = (500+velMusica)/noteDurations[thisNote];
        tone(3, melody[thisNote],noteDuration);
        int pauseBetweenNotes = noteDuration * 1.30;
        delay(pauseBetweenNotes);
        noTone(3);
      }
      else break;
    }
  }
  else noTone(3);
}

ISR(TIMER1_COMPA_vect) {                //ISR es la rutina de interrupcion
  if (start) {
    switch (animate) {
      case 0:

        if (c_animation < AnimacionVelocidad)c_animation++;
        else {
          Blink();
          c_animation = 0;
        }
        break;
      case 1:
        if (c_animation < AnimacionVelocidad)c_animation++;
        else {
          VerticalClean();
          c_animation = 0;
        }
        break;
      case 2:
        if (c_animation < (AnimacionVelocidad / 2))c_animation++;
        else {
          HorizontalClean();
          c_animation = 0;
        }
        break;
      case 3:
        if (c_animation < (AnimacionVelocidad / 100))c_animation++;
        else {
          FillingUp();
          c_animation = 0;
        }
        break;
      default:
        //Funcion de caida
        if (boton) {
          if (contDrop == 0) {
            Drop();
            contDrop = 100;
          }
          else contDrop--;
        }
        else {

          //Desplazamiento del jugador
          if (contShift == 0) {
            rowCheck();
            ContadorDeNivel++;                //Se aumenta el contador de Shifteo
            if (ContadorDeNivel >= nivel[nivelSelector]) { //Si matchea con la velocidad del nivel correspondiente
              hab[0][pos] = 0;                //Luego de hacer la suma o resta correspondiente se muestra la posicion en la matriz
              if (dir) {                      //Depende la direccion
                if (pos > 0)pos--;            //Se baja el valor de pos(columna de posicion) del jugador moviendolo a la izquierda
                else dir = 0;                 //Cuando llega a 0 se invierte dir
              }
              else {
                if (pos < AnchoDeMatriz)pos++;            //Se aumenta el valor de pos(columna de posicion) del jugador moviendolo a la derecha
                else dir = 1;                 //Cuando llega a 4 se invierte dir
              }
              hab[0][pos] = 1;                //Luego de hacer la suma o resta correspondiente se muestra la posicion en la matriz
              ContadorDeNivel = 0;            //Y se resetea el contador de Shifteo
            }
            contShift = 31;
          }
          else contShift--;
        }
        break;
    }
  }
  if (Multiplex) {
    DISPLAY &= ~(1 << 4);
    DISPLAY &= ~15;
    DISPLAY |= nivelSelector;
    Aux1 = nivelSelector & 0b00000010;
    Aux2 = nivelSelector & 0b00001000;
    if (Aux1 == 2) {
      DISPLAY |= (1 << PC3);
    }
    else {
      DISPLAY &= ~(1 << PC3);
    }
    if (Aux2 == 8) {
      DISPLAY |= (1 << PC1);
    }
    else {
      DISPLAY &= ~(1 << PC1);
    }
    DISPLAY |= (1 << 5);
    Multiplex = !Multiplex;
  }
  else {
    DISPLAY &= ~(1 << 5);
    DISPLAY &= ~15;
    DISPLAY |= vida;
    Aux1 = vida & 0b00000010;
    Aux2 = vida & 0b00001000;
    if (Aux1 == 2) {
      DISPLAY |= (1 << PC3);
    }
    else {
      DISPLAY &= ~(1 << PC3);
    }
    if (Aux2 == 8) {
      DISPLAY |= (1 << PC1);
    }
    else {
      DISPLAY &= ~(1 << PC1);
    }
    DISPLAY |= (1 << 4);
    Multiplex = !Multiplex;
  }
  // Serial.println(PORTC);
  //Multiplexado de la matriz
  if (hab[fila][col]) {
    COL |= (15 << 4);
    COL &= ~(1 << col + 4);
    FILA = (1 << fila);
  }
  else {
    COL |= (15 << 4);
    FILA = (0 << fila);
  }
  if (col <= AnchoDeMatriz)col++;
  else {
    col = 0;
    if (fila <= AlturaDeMatriz)fila++;
    else fila = 0;
  }
}

ISR(PCINT2_vect) {
  if (!start) { //MOVER A UNA PCINT
    velMusica=500;
    musica=1;
    win = 0;
    pos = 0;
    vida = VIDAS;
    fila = 0;
    col = 0;
    altura = AlturaDeMatriz;
    nivelSelector = 0;
    Clear();
    animate = 0;
    //Funcion de vacio de la matriz
    start = 1;
    Serial.println("Comienza");
  }
}

ISR(INT0_vect) {
  if (game) {
    EIMSK &= (0 << INT0);
    place = pos;
    if (hab[altura][place]) {
      vida--;
      Serial.print("Te quedan: ");
      Serial.print(vida);
      Serial.println(" vidas");
      if (vida <= 0) {
        Serial.println("PERDISTE");
        //TIMSK1&=(0<<OCIE1A);//Se podria deshabilitar el TIMER1 para detener el juego pero se espera agregar animaciones mejor
        VerticalEdit(0, 0);
        i = altura;
        lost = 1;
        animate = 1;
      }
    }
    boton = true;
  }
}

void Drop() {
  hab[caida][place] = 0;
  if (caida != altura)
    caida++;
  else {
    hab[altura][place] = 1;
    caida = 0;
    boton = false;
    EIMSK |= (1 << INT0);
  }
  hab[caida][place] = 1;

}

int rowCheck() {
  int i;
  int full = 0;
  for (i = 0; i < AnchoDeMatriz + 1; i++) {
    if (hab[altura][i])full++;
  }
  if (full == AnchoDeMatriz + 1) {
    altura--;
    if (altura) {
      nivelSelector++;
      Serial.print("Fila: ");
      Serial.println(altura);
      Serial.print("Nivel: ");
      Serial.println(nivelSelector);
      velMusica=velMusica-100;
    }
    else {
      Clear();
      game = 0;
      animate = 3;
      win = 1;
    }
  }
}

void VerticalEdit(int y, bool value) {
  int i;
  for (i = 0; i < 5; i++) {
    hab[y][i] = value;
  }
}

void HorizontalEdit(int x, bool value) {
  int i;
  for (i = 0; i < 7; i++) {
    hab[i][x] = value;
  }
}

void Clear() {
  int i;
  for (i = 0; i < 5; i++) {
    HorizontalEdit(i, 0);
  }
}

void Full() {
  int i;
  for (i = 0; i < 5; i++) {
    HorizontalEdit(i, 1);
  }
}

void FillingUp() { //animate=3
  if (i < 7) {
    if (j < 5) {
      hab[6 - i][j] = 1;
      j++;
    }
    else {
      j = 0;
      i++;
    }

  }
  else {
    i = 0;
    animate = 0;
  }
}

void HorizontalClean() { //animate=2
  if (i < 5) {
    HorizontalEdit(i, 0);
    i++;
  }
  else {
    animate = 4;
    i = 0;
    game = 1;
    //    Full();
  }
}

void VerticalClean() { //animate=1
  if (i < 7) {
    VerticalEdit(i, 0);
    i++;
  }
  else {
    animate = 5;
    i = 0;
    if (lost) {
      start = 0;
      game = 0;
      boton = false;
      musica=0;
      noTone(3);
      velMusica=500;
      EIMSK |= (1 << INT0);
    }
  }
}

void Blink() {      //animate=0
  if (i < 8) {
    if (i % 2)
      Clear();
    else Full();
    i++;
  }
  else {
    if (!win) {
      animate = 2;
      Full(); //Se vuelve a llenar la matriz solo para probar COMENTAR LINEA
    }
    else {
      musica=0;
      noTone(3);
      start = 0;
    }
    i = 0;
  }
}

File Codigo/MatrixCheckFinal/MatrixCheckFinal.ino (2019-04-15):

#define COL PORTK
#define FILA PORTF

const int out[7]={1,2,4,8,16,32,64};
bool hab[6][5]={
{1,1,1,1,1},
{1,0,0,0,1},
{1,1,1,1,1},
{1,0,0,0,1},
{1,0,0,0,1},
{1,0,0,0,1}
};
volatile int fila=1,col=0;

void setup() {
 
  DDRF=255;
  FILA=1;  
  DDRK=255;
  COL=254;
  Serial.begin(9600);
  cli();                              //deshabilito temporalmente las interrupciones
  TCCR1A=0;                           //limpiamos los registros de control
  TCCR1B=0;                           //del timer 1

  OCR1A=8;            //3 valor minimo, 5 se ve multiplexado en grabacion de 60fps, 8 valor maximo
  TCCR1B|=(1<<WGM12);
  TCCR1B|=(1<<CS10);
  TCCR1B|=(1<<CS12);
  
  
  TIMSK1|=(1<<OCIE1A);                  //enciendo el timer1
  
  sei();                              //activamos las interrupciones

}

void loop() {

}

ISR(TIMER1_COMPA_vect){                 //ISR es la rutina de interrupcion
  if(hab[fila-1][col])
  COL=~(1<<col);
  else COL=~(0<<col);
  FILA=(1<<fila);
  if(col<5)col++;
  else{
    col=0;
    if(fila<6)fila++;
    else fila=1;
  }
}

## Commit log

2019-03-27 Base de programa controlador de la matriz
2019-04-14 Programa de multiplexado de la matriz
2019-04-14 Prueba para implementar GitHub
2019-04-15 Programa de control de boton de jugador y animacion de caida
2019-04-15 Determinado velocidades segun nivel
2019-04-15 Agregada la capacidad de apilar bits con el boton
2019-04-15 Programa de compatibidad entre desplazamiento de usuario y multiplexado de la pantalla
2019-04-15 Programas varios que en conjunto llevaron al primer ensamble del programa final
2019-04-15 Programa principal del juego, ensamble funcional sin limite de juego
2019-04-17 Programa con las funciones de animacion del juego
2019-04-17 Actualizado el changelog
2019-04-21 Agregadas mas funciones para el juego
2019-04-22 Pasadas animaciones de barrido y parpadeo a TIMER
2019-04-23 Pasada funcion restante a TIMER
2019-04-23 Agregadas animaciones de inicio, derrota y victoria, Correccion de falso inicio
2019-04-24 Agregadas declaraciones globales al juego para mejor y mas simple configuracion del juego
2019-04-24 Programa de display de vidas y niveles
2019-04-24 Acoplado del control de display con el programa principal
2019-05-31 Arreglada compatibilidad en cambio de macros
    [Bitris.ino]
2019-06-04 Mejorada compatibilidad con diversas cantidades de filas y columnas
2019-08-16 Actualizacion de README
2019-08-17 Agregado informe y circuitos de displays
    [Display de vidas y nivel.brd, Display de vidas y nivel.sch]
2019-08-18 Agregado archivo DWG del modelo 3D del gabinete del Bitrix
    [GabineteMatrizVertical.dwg]
2019-08-20 Actualizacion del repositorio y agregado diseño 3D del gabinete
    [BitrisATMEGA.brd, BitrisATMEGA.sch, Display de vidas y nivel.brd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]
2019-08-21 PCB modificado
    [BitrisATMEGA.brd, BitrisATMEGA.sch]
2019-09-17 PCB 2.0
    [BitrisATMEGA.brd, BitrisATMEGA.sch]
2019-09-23 Modelos 3D del juego: Matriz y rampa de monedas
    [MatrizLED.dwg, Monedas.dwg]
2019-10-09 Añadido archivos varios de diferentes piezas del gabinete para guia de tamaños y diseño e impresion 3D
    [BackCase.stl, GabineteDividido.dwg, LowCaseBitrix.stl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]
2019-10-10 Agrego de codigo Bitris Pago
2019-10-24 Update menor del PCB de Displays
2019-11-08 Añadidos ficheros y datos de la musica de fondo
2019-11-08 Agregado esquematico de la mini placa del Parlante
    [Parlante.sch]
2019-11-10 Añadido diagrama de flujo y fix menor de la musica
    [BitrisUNO.ino]
2019-11-10 Limpieza del diseño principal
    [BitrisATMEGA.brd, BitrisATMEGA.sch]
2019-11-11 Ajuste SCH
    [BitrisATMEGA.brd, BitrisATMEGA.sch]
2019-11-11 Arreglado problemas de musica y programa pago
    [BitrisPAGO.ino, BitrisUNO.ino]
2019-11-12 PCB DISPLAYs
    [Display de vidas y nivel.brd]
2019-11-12 Actualizado informe
    [BitrisATMEGA.brd, BitrisATMEGA.sch]
